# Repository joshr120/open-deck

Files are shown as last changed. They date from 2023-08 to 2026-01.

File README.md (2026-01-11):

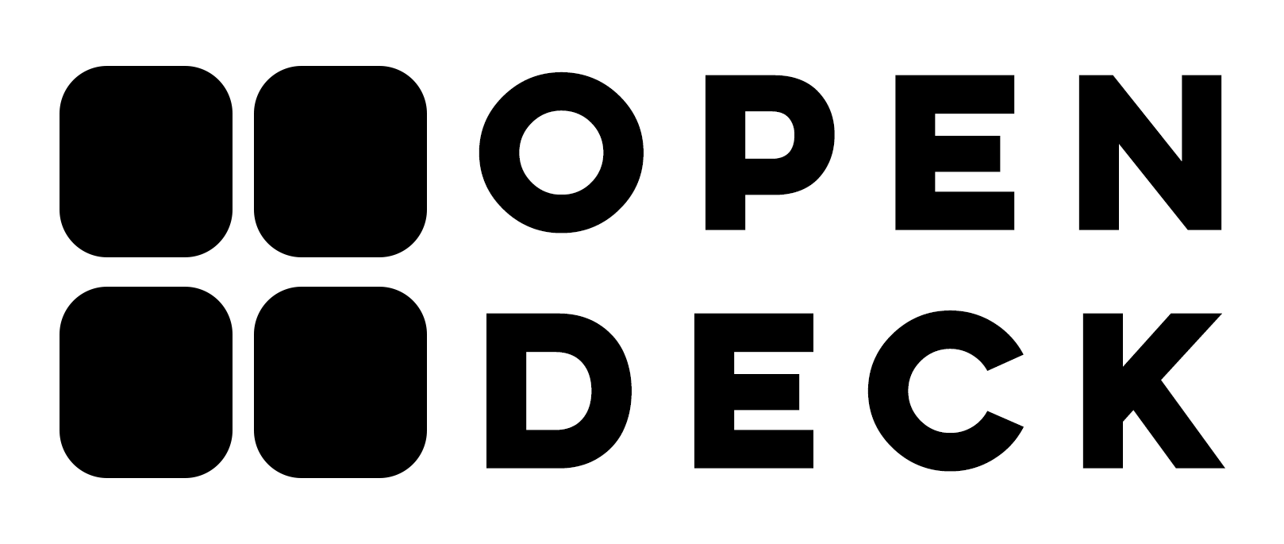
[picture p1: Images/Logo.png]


# Open Deck

## Parts and fully assembled units can be purchased Here: [https://thingsbyjosh.com/products/open-deck-macro-keyboard](https://thingsbyjosh.com/products/open-deck-macro-keyboard)  
<br>

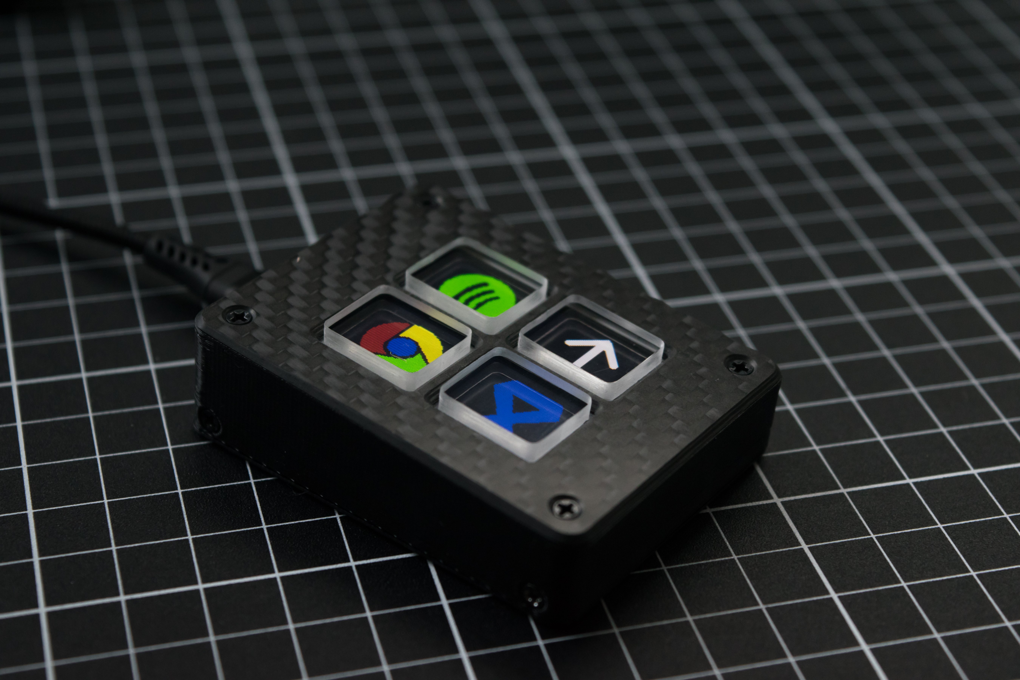
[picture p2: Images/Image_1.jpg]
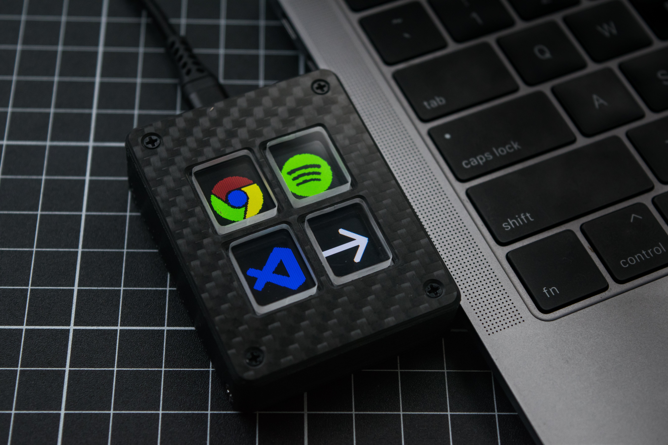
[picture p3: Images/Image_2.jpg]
⠀⠀⠀⠀⠀⠀⠀

Open Deck is a low cost open source macro keyboard with a customizable image behind every key.

Open Deck is an open source macro keyboard designed to be a cheaper alternative to the stream deck. It has software to easily change the images as well as the macros assigned to each button. The folder Structure allows 6 different apps to be configured with 3 macro keys each. The software allows the open deck to update with whatever app is open as well as open an app when buttons are pressed.

An easy to use interface allows you to easily upload and set macros.

MQTT Support to interface with home assistant.

Full Video and build guide here: https://youtu.be/SCIMHQAToSw

# Software:

## GUI Interface

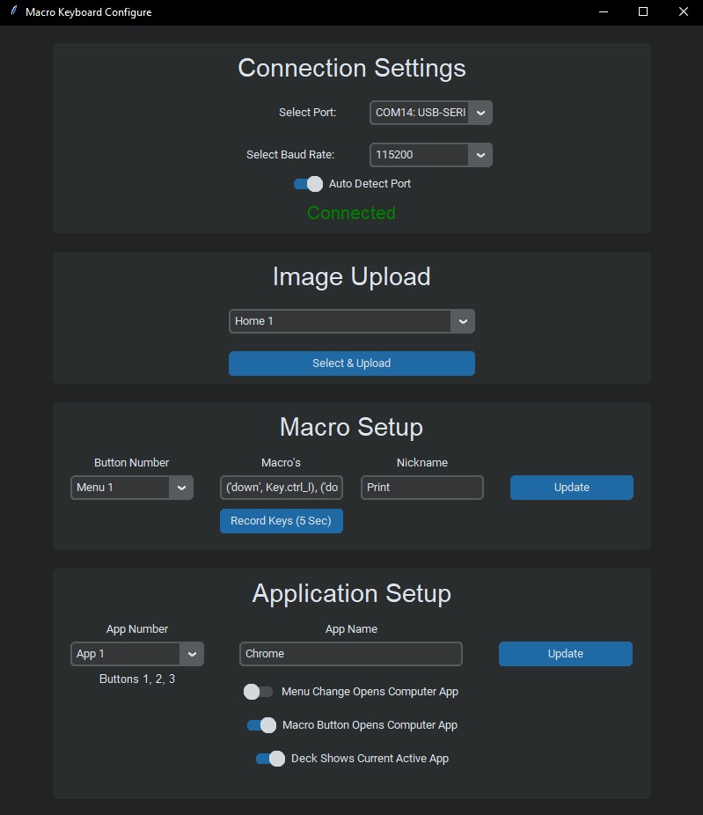
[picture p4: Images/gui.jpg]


Provided is a pre-compiled program for windows and mac as well as all the source code (written in python). Extract the zipped folder and run the .exe (or mac equivalent), no python libary installs required.

The Open Deck communicates with a PC over a serial USB connection. The software can automatically detect and connect to the Open Deck when it is plugged in.

The program is first used to upload images and set the macro's. After that it runs in the background to send keystrokes when the buttons are pressed.

Note: the automatic window switching only works on windows currently and the macOS pre-compiled GUI has only been tested on macOS Big Sur 11.6

## Uploading Images
The PC application makes it super easy to upload images. The files can be any size and the program does all of the conversion for you. At the moment each image can only be a single colour when uploaded through the GUI. When uploading an image the black part of the image will be shown in the chosen colour and the rest will be black. See Additional Features section for how to do images with multiple colours.

The select & upload button will prompt the user to select an image from the file system as well as choose a colour from a colour picker.

## Setting Macros
The macros are sent using the python [pynput library] (https://pynput.readthedocs.io/en/latest/keyboard.html#controlling-the-keyboard). (Previous version used the python keyboard library but this had limitations)

If more complex macros are required I recommend setting it to some unused combination and then remapping this combination using something like auto hot key. (Not going to try re-invent the wheel here). Easier way to figure out the format or key names is to use the record keys button in the GUI and look at what is entered in the text box. For example the following input will output "test" when the macro is triggered:

<code>('down', 't'), ('up', 't'), ('down', 'e'), ('up', 'e'), ('down', 's'), ('up', 's'), ('down', 't'), ('up', 't')</code>

To do key combinations such as "control+shift" it would look like this:

<code>('down', Key.ctrl), ('down', Key.ctrl), ('down', Key.ctrl), ('down', 's'), ('up', 's'), ('up', Key.ctrl)</code> 

## Window Switching/application setup
One usefull feature on the open deck has is the ability to have the buttons change depending on which application is currently open as well. It can also open an app when a button on the open deck is pressed.

By inputting the application name for each menu of the open deck, the program will look for a window containing this name to either control the open deck or have the open deck control/activate this window.

On windows there are 3 settings for automatically switching windows and/or current open deck state.

- The first option will open the application on the computer when the corresponding folder is opened on the keypad.

- The second option will open the corresponding computer application when a shortcut is sent. This is usefull if you have multiple applciations open at once as it will make the correct application active before sending the keystrokes.

- The third option will change which set of macros are shown on the keypad depending on which computer application is currently active.

## Arduino
All of the code running on the ESP8266 on the Open Deck itself is using arduino. The images are stored as a bitmap in SPIFFS so that they remain after a power cycle and are not relient on a computer connection.

When a key is pressed it sends a correlated number (1-16) over serial to the program running on the computer. 

If you purchase a pre-made Open Deck it will come flashed with the default firmware and you will not need to touch any arduino code or install any libraries. 
> For more info on the software see the README in the Code folder

## Smart Home Control With MQTT:
The Open Deck can also be used as a smart home controller using MQTT. This can easily interface with home assitant without the Open-Deck only needing to be plugged in for power. Upload the example MQTT arduino sketch onto the Open Deck and enter your credentials in the code. 

A number 1-16 will be sent to the topic ```open_deck/buttons``` whenever the button is pressed.

Images can easily be uploaded using the GUI and will be saved localy on the Open Deck.

In the future I would like to integrate this setup into the GUI so you do not need to re-flash any firmware.

# Hardware
See the BOM for a full list of all of the required components. And support the project by buying parts or a full unit [here](https://thingsbyjosh.com/products/open-deck-macro-keyboard)

> If there is a particular item or set of items you would like to buy feel free to send me an email to [info@thingsbyjosh.com](info@thingsbyjosh.com).

Things of Note:

- The display is a 128x160 tft display. The exact display is quite important as the hole patten and pinout needs to fit the custom PCB's. (See BOM for Link)

- An ESP8266 is being used as the micro-controller as it is small, low cost, has enough flash memory to store all of the images as well as having WiFi to allow for additional features. Importantly for everything to fit this needs to be a WEMOS D1 Mini V4 with a USB-C Connector

- Low Profile M2 Screws used for clearance (Length is critical)

## 3D Printed Parts
All parts can be printed with no supports. Print in the orientation shown below:

Body:

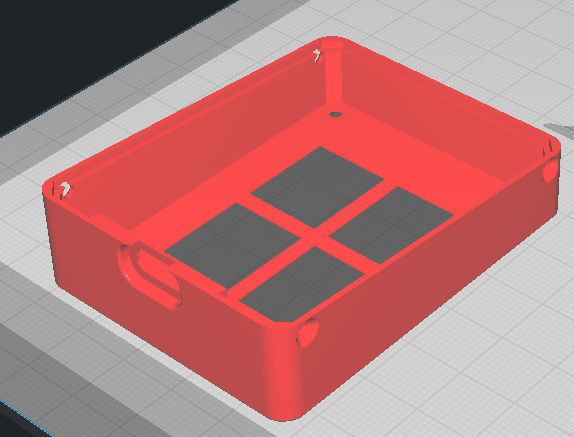
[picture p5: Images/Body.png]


Bottom Cover:

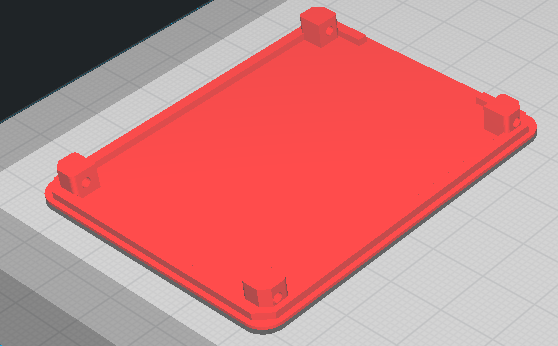
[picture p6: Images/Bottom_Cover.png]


Window Holder:

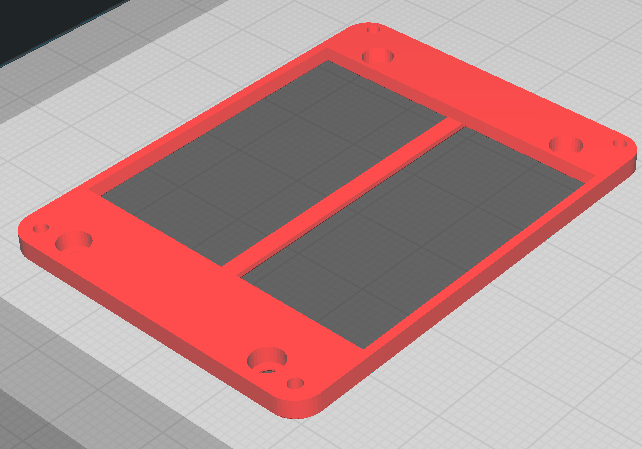
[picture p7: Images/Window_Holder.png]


Spacer:

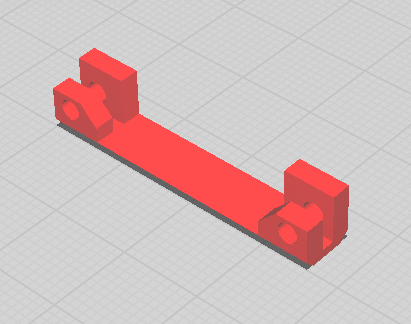
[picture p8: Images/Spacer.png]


## CNC Machined Parts
### Carbon Fibre Top Plate
The carbon top plate is made out of 1mm thick carbon fibre.

### Acrylic Key Caps
The 'Key Caps' are machined out of 4.5mm thick acrylic. They are all the same design.

These can also be made out of 1.5mm and 3mm laser cut acrylic glued together if you do not have access to a CNC. I have found the best glue for this is UV curable glue used for some phone screen protectors.

These could also potentially be 3D printed from clear resin and polished to get a transparent finish.

As with all the custom parts these are availale for purchase from [my store](https://thingsbyjosh.com/products/open-deck-macro-keyboard).

## PCB
The PCB folder contains a zipped folder of the GERBER files required to have the PCB manufactured. 

If you want to order them yourself you can support the project and order them here: [PCBWay.com](https://pcbway.com/g/heg1oh).

# Additional Features:
- If you want images with multiple colours these currently need to be manually entered into the arduino code. See the README in the Code folder for more info.

<br>
<br>

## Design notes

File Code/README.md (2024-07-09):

# Open Deck Software

## Parts and fully assembled units can be purchased Here: https://www.tindie.com/products/27756/  
<br>

# Software:
## Uploading Images
The PC application makes it super easy to upload images. The files can be any size and the program does all of the conversion for you. At the moment each image can only be a single colour when uploaded through the GUI. When uploading an image the black part of the image will be shown in the chosen colour and the rest will be black. See Additional Features section for how to do images with multiple colours.

## Arduino
All of the code running on the ESP8266 on the Open Deck itself is using arduino. The images are stored as a bitmap in SPIFFS so that they remain after a power cycle and are not relient on a computer connection.

When a key is pressed it sends a correlated number (1-16) over serial to the program running on the computer. 

## MQTT
Thanks to the WiFi enable esp8266 chip the Open Deck can also be used as a smart home controller using MQTT. This can easily interface with home assitant without the Open-Deck only needing to be plugged in for power. Upload the example MQTT arduino sketch onto the Open Deck and enter your credentials in the code. 

This version of the code also allows the orientation to be changed so that the cable can come out of the bottom and the display can tilt slightly upwares for wall mounting.

A number 1-16 will be sent to the topic ```open_deck/buttons``` whenever the button is pressed.

Images can easily be uploaded using the GUI and will be saved localy on the Open Deck.

In the future I would like to integrate this setup into the GUI so you do not need to re-flash any firmware.

# Additional Features:
If you want images with multiple colours these currently need to be manually entered into the arduino code. The bitmap in the correct format will be outputted when an image is uploaded using the source python file "full_gui.py". One image will needed to be made for each colour in the image. A pre-made example of this can be uncommented for a chrome logo. Final imges are 48x72 pixels stored as a bitmap. The last 3 bytes of the message sent over serial contain the RGB colour of the icon.

Replace:

        tft.drawBitmap(0,0,homes[1], 54, 70, homeColours[1]);  //comment out this line to use chrome mulit-colour example

With:

        /////////    Chrome Multi-colour example  ///////
          tft.drawBitmap(0,0,chrome_r, 54, 70, ST77XX_RED);   
          tft.drawBitmap(0,0,chrome_g, 54, 70, ST77XX_GREEN);
          tft.drawBitmap(0,0,chrome_b, 54, 70, ST77XX_BLUE);
          tft.drawBitmap(0,0,chrome_y, 54, 70, ST77XX_YELLOW);

Where chrome_r, chrome_g etc. are individual bitmaps of each coloured reigon stored in the bitmaps.h file. The colour of each bitmap can then manually be set (eg. ST77XX_RED, (RGR565 format)) 

Note:  When uploading one of the macro images two images will be printed. The second is a smaller version used for the key press effect.
        
<br>
<br>

# Notes:
- Feel free to reach out with any question/problems and I will try to help
- The sofware is still evolving and I am by no means a software engineer but I have been using it everyday for over 6 months without an major issues.
- For use with MacOS you may need to install the FTDI drivers from [here](https://ftdichip.com/Drivers/vcp-drivers/)

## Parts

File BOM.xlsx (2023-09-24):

Open Deck BOM
Buy Open Deck & Parts Here: (https://www.tindie.com/products/27756) | https://www.tindie.com/products/27756
Custom Parts:
Item: | QTY: | Link:
PCB | 1 | https://www.tindie.com/products/27756
Acrylic Key Caps | 4 | https://www.tindie.com/products/27756
Carbon Fibre Top Cover | 1 | https://www.tindie.com/products/27756
3D Printed Parts:
Item: | QTY:
Body | 1
Bottom Cover | 1
Spacer | 2
Window Holder | 1
Off The Shelf Parts:
Item: | QTY: | Link:
ESP8266 (D1 Mini V4) | 1 | AliExpress (https://www.aliexpress.com/item/32831353752.html)
1.8" TFT Display | 1 | AliExpress (https://www.aliexpress.com/item/32996979276.html)
Switches | 4 | AliExpress (https://www.aliexpress.com/item/4001343124925.html)
10kΩ 0805 Resistor | 2 | AliExpress (https://www.aliexpress.com/item/2011573653.html)
Low Profile M2*10mm | 4 | AliExpress (https://www.aliexpress.com/item/1005005264656436.html)
M2 Nut | 4 | AliExpress (https://www.aliexpress.com/item/32977174437.html)
M2*6mm Countersunk Screw | 8 | AliExpress (https://www.aliexpress.com/item/33043885403.html)
Non-slip Feet (0.5mm) | 1 | AliExpress (https://www.aliexpress.com/item/1005003972280242.html)

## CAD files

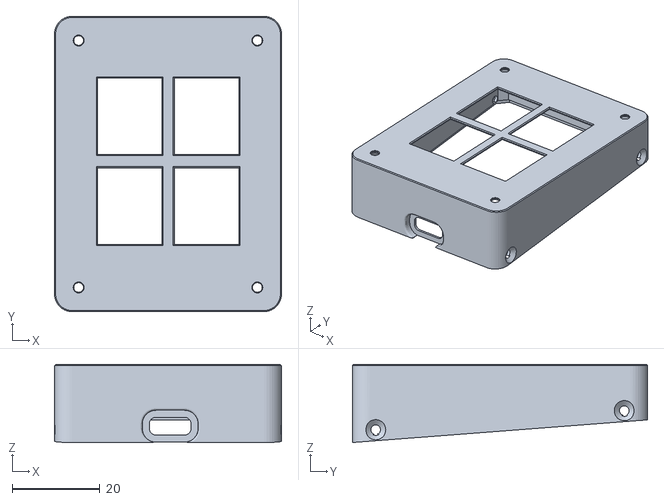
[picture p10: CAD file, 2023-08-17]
Hardware/3D Printed Parts/Body For Carbon (4.5mm acrylic).stl
51.7 x 67.2 x 17.8

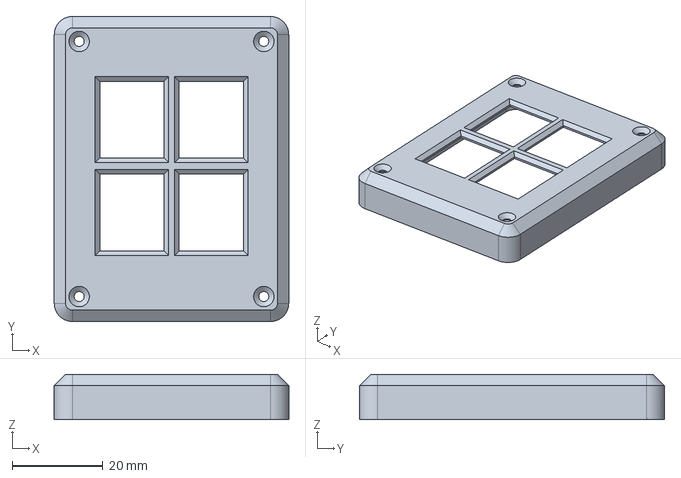
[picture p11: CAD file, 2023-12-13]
Hardware/Aluminium Version/Macro Keyboard Aluminium Top.step
51.7 x 67.2 x 10.0 mm

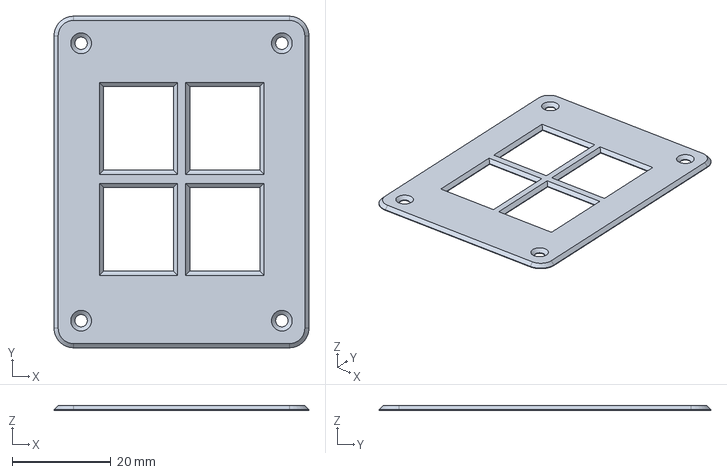
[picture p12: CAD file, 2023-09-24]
Hardware/CNC Machined Parts/Carbon Fibre Top Plate.step
51.7 x 67.2 x 1.00 mm

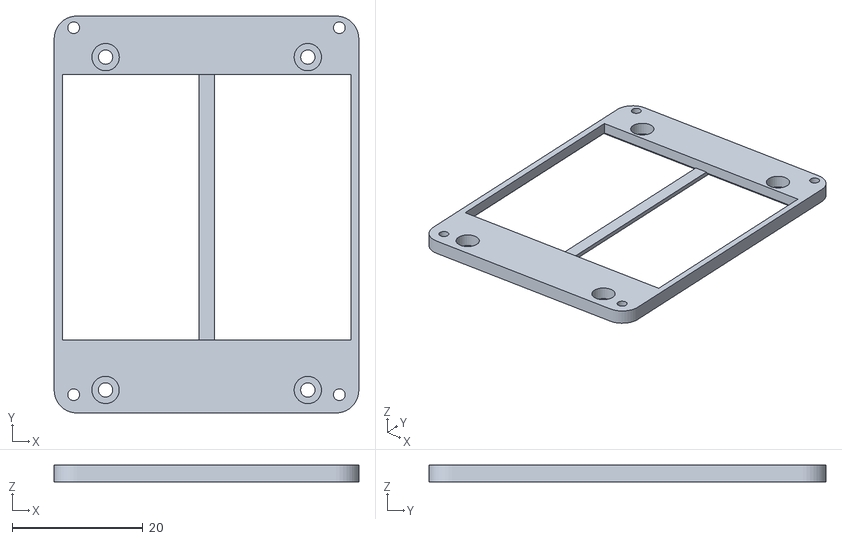
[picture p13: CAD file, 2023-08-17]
Hardware/3D Printed Parts/Window Holder (4.5mm windows).stl
46.7 x 60.8 x 2.55

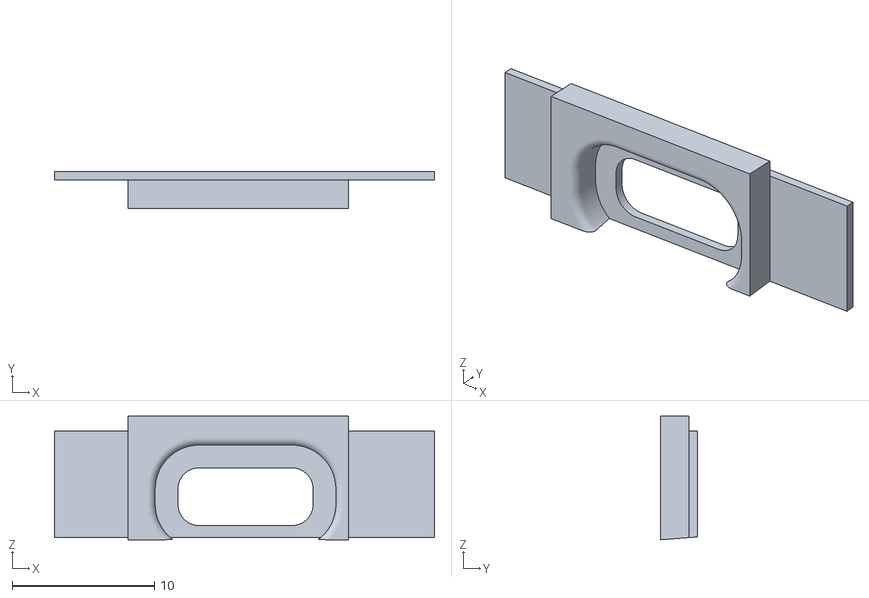
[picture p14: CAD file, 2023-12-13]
Hardware/Aluminium Version/USB housing.stl
26.7 x 2.60 x 8.68

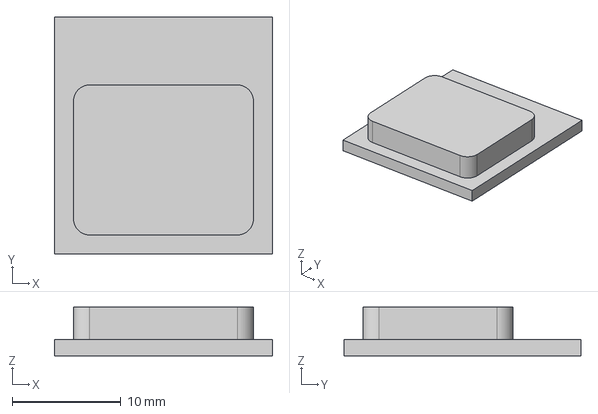
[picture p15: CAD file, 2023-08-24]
Hardware/CNC Machined Parts/Acrylic Keycap.step
20.1 x 21.8 x 4.50 mm

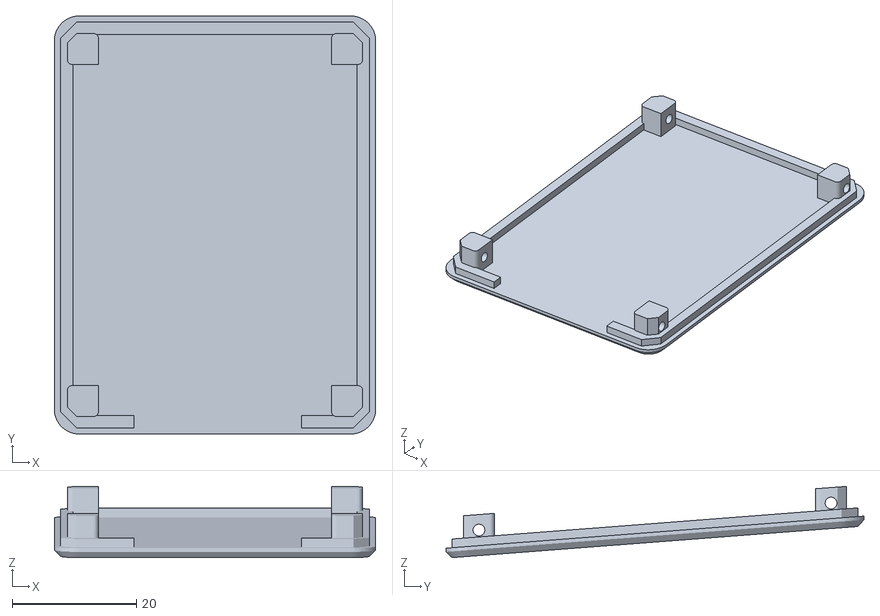
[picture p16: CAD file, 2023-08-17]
Hardware/3D Printed Parts/Bottom Plate (4.5mm acrylic).stl
51.7 x 67.2 x 11.5

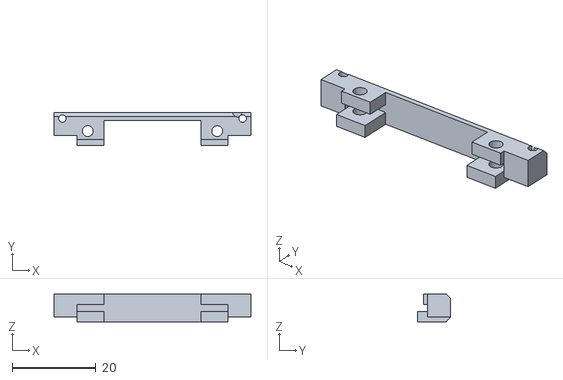
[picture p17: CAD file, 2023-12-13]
Hardware/Aluminium Version/Aluminium Front Spacer.stl
47.2 x 8.00 x 6.60

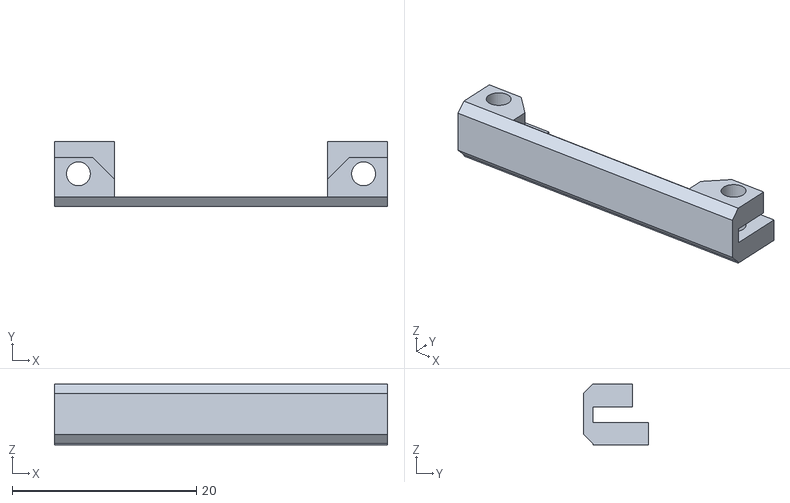
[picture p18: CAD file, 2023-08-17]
Hardware/3D Printed Parts/Microswitch Spacer 2.stl
36.2 x 7.04 x 6.60

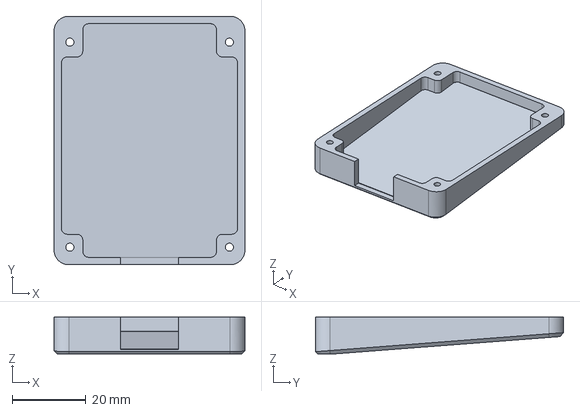
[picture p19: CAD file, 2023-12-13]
Hardware/Aluminium Version/Macro Keyboard Aluminium Bottom.step
51.7 x 67.2 x 10.0 mm

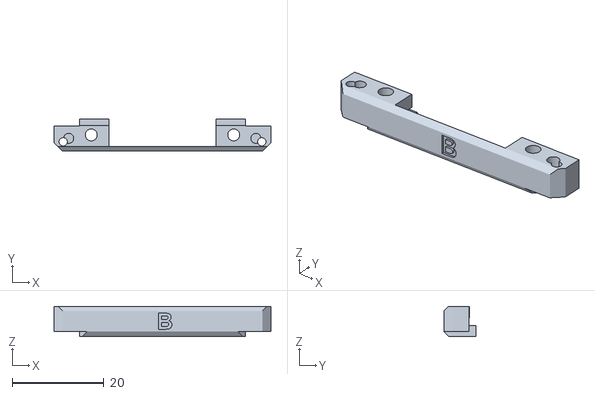
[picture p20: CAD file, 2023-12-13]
Hardware/Aluminium Version/Aluminium Back Spacer.stl
47.2 x 7.04 x 6.60

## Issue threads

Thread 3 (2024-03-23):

Can you support more integrated devices?

lukedoomer, 2024-03-23:
Your design is awesome. I hope you can support more common esp32-s3 devices. for example [wt32-sc01](https://www.openhasp.com/0.6.1/devices/wt32-sc01/) by wireless tag

joshr120, 2024-03-23:
Not too sure what you mean by support more devices? This has a custom PCB specifically designed for the ESP8266 Wemos D1 V3 so you can't really just drop in a different microcontroller. The code would be fairly easy to get working on an ESP32 and if I do make an updated version it would probably use an ESP32

Closed 2024-06-06.

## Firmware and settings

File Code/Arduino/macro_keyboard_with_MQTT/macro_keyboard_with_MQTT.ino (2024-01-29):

///////////////////////////////
////////  OPEN DECK   /////////
///////////////////////////////

/////  MQTT Setup ///////
// Using: https://github.com/plapointe6/EspMQTTClient

#include "EspMQTTClient.h"

EspMQTTClient client(
  "YOUR_SSID",  //WIFI SSID
  "YOUR_PASSWORD",  //WIFI Password
  "192.168.1.204",  // MQTT Broker server ip (REPLACE WITH YOURS)
  "MQTT_USERNAME",   // Can be omitted if not needed
  "MQTT_USERNAME",   // Can be omitted if not needed
  "Open Deck"      // Client name that uniquely identify your device
);

//////  end MQTT setup ///////


/////// Set Screen Orientation////////
int orientation = 0; //2 for normal 0 for inverted
/////////////////////////////////////

#include <Adafruit_GFX.h>    // Core graphics library
#include <Adafruit_ST7735.h> // Hardware-specific library for ST7735
#include <Adafruit_ST7789.h> // Hardware-specific library for ST7789
#include <SPI.h>

#include <FS.h> //for saving in spiffs
#include "bitmap.h"
#include "home_bitmaps.h"
#include "menu_bitmaps.h"

#define TFT_CS     D8 
#define TFT_RST    D6  // Theoreically can set this to -1 use use arduino reset (wasnt working)
#define TFT_DC     D2



////////////////////////////
//      PCB Pinouts       //
////////////////////////////
#define TL D0
#define BL A0   //Note Analog pin being used with pull up resistor as run out of digital inputs (Fix in future versions)
#define TR D1
#define BR D4


// For 1.44" and 1.8" TFT with ST7735 use
Adafruit_ST7735 tft = Adafruit_ST7735(TFT_CS, TFT_DC, TFT_RST);

int pageState = 1;
int lastPageState = 0;

int menuState = 0;
int lastMenuState = 0;

int incomingByte = 0;

#define BUFF_LEN 490
unsigned char img1 [BUFF_LEN];
unsigned char colour [3];

//Colours stored in RBG565 format (see https://www.barth-dev.de/online/rgb565-color-picker/)
//These are the default colours, once updated using the GUI stored and loaded in from SPIFFS
uint16_t homeColours [] = {0, 0xF800, 0x07E0, 0x001F, 0xFC18, 0xFFE0, 0x07FF};
uint16_t menuColours [] = {0, 0xF800, 0xF800, 0xF800, 0x07E0, 0x07E0, 0x07E0, 0x001F, 0x001F, 0x001F, 0xFC18, 0xFC18, 0xFC18, 0xFFE0, 0xFFE0, 0xFFE0, 0x07FF, 0x07FF, 0x07FF};

unsigned char writeBuffer [492]; //array to store in spiffs 490 bits of the image and 2 bit on the end of the colour

void setup(void) {
  pinMode(TL, INPUT);
  pinMode(TR, INPUT_PULLUP);
  pinMode(BL, INPUT);
  pinMode(BR, INPUT_PULLUP);
  Serial.begin(115200);
  Serial.setTimeout(500);
  tft.initR(INITR_BLACKTAB);   // initialize a ST7735S chip, black tab
  tft.fillScreen(ST77XX_BLACK);

  //Serial.println("Initialized");

  delay(100);

  tft.setRotation(orientation);  //invert diaply orientation

  readFromSpiffs();

}

//MQTT on connection
void onConnectionEstablished() {
  Serial.println("MQTT Established");

//  client.subscribe("open_deck/buttons", [] (const String &payload)  {
//    Serial.println(payload);
//  });

  client.publish("open_deck/buttons", "Connected");
}

void loop() {
    client.loop(); //MQTT

    bool TLState = 0;
    bool BRState = 0;
    bool BLState = 0;
    bool TRState = 0; 
    int BLVal = 1000;
    int TRVal = 1000;
    
    if (orientation == 2){
      TLState = digitalRead(TL);
      BRState = digitalRead(BR);
      TRState = digitalRead(TR);
      BLVal = analogRead(BL);  //analog read as not enough digital pins :(
      BLState = (BLVal>500);
    } else if (orientation == 0){
      TLState = digitalRead(BR);
      BRState = digitalRead(TL);
      BLState = digitalRead(TR);
      TRVal = analogRead(BL);  //analog read as not enough digital pins :(
      TRState = (TRVal>500);
    }

    //page 1
    if (pageState == 1 && !TLState){  //top left page 1
      //Serial.println("Entering Chrome Menu");
      menuState = 1;
      pageState = 0;
      lastPageState = 0;
    } else if (pageState == 1 && !TRState){ //top Right page 1
      menuState = 2;
      pageState = 0;
      lastPageState = 0;
    } else if (pageState == 1 && !BLState){  //Bottom left page 1
      menuState = 3;
      pageState = 0;
      lastPageState = 0;
    } else if (pageState == 1 && !BRState){  //next page pressed page 1
      pageState = 2;
    } else if ((pageState == 0 && menuState <= 3) && !BLState){  //home pressed from menu 1-3
      pageState = 1;
      menuState = 0;
      lastMenuState = 0;
    }
    
    //page 2
    else if (pageState == 2 && !TLState){  //top left page 2
      menuState = 4;
      pageState = 0;
      lastPageState = 0;
    } else if (pageState == 2 && !TRState){ //top Right page 2
      menuState = 5;
      pageState = 0;
      lastPageState = 0;
    } else if (pageState == 2 && !BLState){  //prev page
      pageState = 1;
    } else if (pageState == 2 && !BRState){  //bottom right page 2
      menuState = 6;
      pageState = 0;
      lastPageState = 0;
    } else if ((pageState == 0 && menuState >= 4) && !BLState){  //home pressed from menu 4-6
      pageState = 2;
      menuState = 0;
      lastMenuState = 0;
    }

    //Menu 1        
    else if (menuState == 1 && !TLState){
      tft.fillRect(0,0,54, 70, ST77XX_BLACK);
      tft.drawBitmap(0,0,menus_small[1], 54, 70, menuColours[1]);
      Serial.println("1");
      client.publish("open_deck/buttons", "1");
      delay(150);
      if (orientation == 2){
        while(!TLState){ TLState = digitalRead(TL);delay(10);}
      }  else if (orientation == 0){ //work around for analog read 
        while(!TLState){ TLState = digitalRead(BR);delay(10);}
      }
      tft.drawBitmap(0,0,menus[1], 54, 70, menuColours[1], ST77XX_BLACK);
      
    } else if (menuState == 1 && !TRState){
      tft.fillRect(74, 0, 54, 70, ST77XX_BLACK);
      tft.drawBitmap(74,0,menus_small[2], 54, 70, menuColours[2]);
      Serial.println("2");
      client.publish("open_deck/buttons", "2");
      delay(150);
      if (orientation == 2){
        while(!TRState){ TRState = digitalRead(TR);delay(10);}
      }  else if (orientation == 0){ //work around for analog read 
        while(!TRState){ TRState =  TRVal = analogRead(BL); TRState = (TRVal>500); delay(10);}
      }
      tft.drawBitmap(74,0,menus[2], 54, 70, menuColours[2], ST77XX_BLACK);
      
    } else if (menuState == 1 && !BRState){
      tft.fillRect(74, 90, 54, 70, ST77XX_BLACK);
      tft.drawBitmap(74, 90, menus_small[3], 54, 70, menuColours[3]);
      Serial.println("3");
      client.publish("open_deck/buttons", "3");
      delay(150);
      if (orientation == 2){
        while(!BRState){ BRState = digitalRead(BR);delay(10);}
      }  else if (orientation == 0){ //work around for analog read 
        while(!BRState){ BRState = digitalRead(TL);delay(10);}
      }
      tft.drawBitmap(74,90,menus[3], 54, 70, menuColours[3], ST77XX_BLACK);
    }

    //Menu 2
    else if (menuState == 2 && !TLState){
      tft.fillRect(0,0,54, 70, ST77XX_BLACK);
      tft.drawBitmap(0,0,menus_small[4], 54, 70, menuColours[4], ST77XX_BLACK);
      Serial.println("4");
      client.publish("open_deck/buttons", "4");
      delay(150);
      if (orientation == 2){
        while(!TLState){ TLState = digitalRead(TL);delay(10);}
      }  else if (orientation == 0){ //work around for analog read 
        while(!TLState){ TLState = digitalRead(BR);delay(10);}
      }
      tft.drawBitmap(0,0,menus[4], 54, 70, menuColours[4], ST77XX_BLACK);
      
    } else if (menuState == 2 && !TRState){
      tft.fillRect(74, 0, 54, 70, ST77XX_BLACK);
      tft.drawBitmap(74,0,menus_small[5], 54, 70, menuColours[5]);
      Serial.println("5");
      client.publish("open_deck/buttons", "5");
      delay(150);
      if (orientation == 2){
        while(!TRState){ TRState = digitalRead(TR);delay(10);}
      }  else if (orientation == 0){ //work around for analog read 
        while(!TRState){ TRState =  TRVal = analogRead(BL); TRState = (TRVal>500); delay(10);}
      }
      tft.drawBitmap(74,0,menus[5], 54, 70, menuColours[5], ST77XX_BLACK);
      
    } else if (menuState == 2 && !BRState){
      tft.fillRect(74, 90, 54, 70, ST77XX_BLACK);
      tft.drawBitmap(74, 90, menus_small[6], 54, 70, menuColours[6]);
      Serial.println("6");
      client.publish("open_deck/buttons", "6");
      delay(150);
      if (orientation == 2){
        while(!BRState){ BRState = digitalRead(BR);delay(10);}
      }  else if (orientation == 0){ //work around for analog read 
        while(!BRState){ BRState = digitalRead(TL);delay(10);}
      }
      tft.drawBitmap(74,90,menus[6], 54, 70, menuColours[6], ST77XX_BLACK);
    }

    //Menu 3
    else if (menuState == 3 && !TLState){
      tft.fillRect(0,0,54, 70, ST77XX_BLACK);
      tft.drawBitmap(0,0,menus_small[7], 54, 70, menuColours[7]);
      Serial.println("7");
      client.publish("open_deck/buttons", "7");
      delay(150);
      if (orientation == 2){
        while(!TLState){ TLState = digitalRead(TL);delay(10);}
      }  else if (orientation == 0){ //work around for analog read 
        while(!TLState){ TLState = digitalRead(BR);delay(10);}
      }
      tft.drawBitmap(0,0,menus[7], 54, 70, menuColours[7], ST77XX_BLACK);
      
    } else if (menuState == 3 && !TRState){
      tft.fillRect(74, 0, 54, 70, ST77XX_BLACK);
      tft.drawBitmap(74,0,menus_small[8], 54, 70, menuColours[8]);
      Serial.println("8");
      client.publish("open_deck/buttons", "8");
      delay(150);
      if (orientation == 2){
        while(!TRState){ TRState = digitalRead(TR);delay(10);}
      }  else if (orientation == 0){ //work around for analog read 
        while(!TRState){ TRState =  TRVal = analogRead(BL); TRState = (TRVal>500); delay(10);}
      }
      tft.drawBitmap(74,0,menus[8], 54, 70, menuColours[8], ST77XX_BLACK);
      
    } else if (menuState == 3 && !BRState){
      tft.fillRect(74, 90, 54, 70, ST77XX_BLACK);
      tft.drawBitmap(74, 90, menus_small[9], 54, 70, menuColours[9]);
      Serial.println("9");
      client.publish("open_deck/buttons", "9");
      delay(150);
      if (orientation == 2){
        while(!BRState){ BRState = digitalRead(BR);delay(10);}
      }  else if (orientation == 0){ //work around for analog read 
        while(!BRState){ BRState = digitalRead(TL);delay(10);}
      }
      tft.drawBitmap(74,90,menus[9], 54, 70, menuColours[9], ST77XX_BLACK);
    }

    //Menu 4 (task manger)
    else if (menuState == 4 && !TLState){
      tft.fillRect(0,0,54, 70, ST77XX_BLACK);
      tft.drawBitmap(0,0,menus_small[10], 54, 70, menuColours[10]);
      Serial.println("10");
      client.publish("open_deck/buttons", "10");
      delay(150);
      if (orientation == 2){
        while(!TLState){ TLState = digitalRead(TL);delay(10);}
      }  else if (orientation == 0){ //work around for analog read 
        while(!TLState){ TLState = digitalRead(BR);delay(10);}
      }
      tft.drawBitmap(0,0,menus[10], 54, 70, menuColours[10], ST77XX_BLACK);
      
    } else if (menuState == 4 && !TRState){
      tft.fillRect(74, 0, 54, 70, ST77XX_BLACK);
      tft.drawBitmap(74,0,menus_small[11], 54, 70, menuColours[11]);
      Serial.println("11");
      client.publish("open_deck/buttons", "11");
      delay(150);
      if (orientation == 2){
        while(!TRState){ TRState = digitalRead(TR);delay(10);}
      }  else if (orientation == 0){ //work around for analog read 
        while(!TRState){ TRState =  TRVal = analogRead(BL); TRState = (TRVal>500); delay(10);}
      }
      tft.drawBitmap(74,0,menus[11], 54, 70, menuColours[11], ST77XX_BLACK);
      
    } else if (menuState == 4 && !BRState){
      tft.fillRect(74, 90, 54, 70, ST77XX_BLACK);
      tft.drawBitmap(74, 90, menus_small[12], 54, 70, menuColours[12]);
      Serial.println("12");
      client.publish("open_deck/buttons", "12");
      delay(150);
      if (orientation == 2){
        while(!BRState){ BRState = digitalRead(BR);delay(10);}
      }  else if (orientation == 0){ //work around for analog read 
        while(!BRState){ BRState = digitalRead(TL);delay(10);}
      }
      tft.drawBitmap(74,90,menus[12], 54, 70, menuColours[12], ST77XX_BLACK);
    }

    //Menu 5
    else if (menuState == 5 && !TLState){
      tft.fillRect(0,0,54, 70, ST77XX_BLACK);
      tft.drawBitmap(0,0,menus_small[13], 54, 70, menuColours[13]);
      Serial.println("13");
      client.publish("open_deck/buttons", "13");
      delay(150);
      if (orientation == 2){
        while(!TLState){ TLState = digitalRead(TL);delay(10);}
      }  else if (orientation == 0){ //work around for analog read 
        while(!TLState){ TLState = digitalRead(BR);delay(10);}
      }
      tft.drawBitmap(0,0,menus[13], 54, 70, menuColours[13], ST77XX_BLACK);
      
    } else if (menuState == 5 && !TRState){
      tft.fillRect(74, 0, 54, 70, ST77XX_BLACK);
      tft.drawBitmap(74,0,menus_small[14], 54, 70, menuColours[14]);
      Serial.println("14");
      client.publish("open_deck/buttons", "14");
      delay(150);
      if (orientation == 2){
        while(!TRState){ TRState = digitalRead(TR);delay(10);}
      }  else if (orientation == 0){ //work around for analog read 
        while(!TRState){ TRState =  TRVal = analogRead(BL); TRState = (TRVal>500); delay(10);}
      }
      tft.drawBitmap(74,0,menus[14], 54, 70, menuColours[14], ST77XX_BLACK);
      //delay(100);
      
    } else if (menuState == 5 && !BRState){
      tft.fillRect(74, 90, 54, 70, ST77XX_BLACK);
      tft.drawBitmap(74, 90, menus_small[15], 54, 70, menuColours[15]);
      Serial.println("15");
      client.publish("open_deck/buttons", "15");
      delay(150);
      if (orientation == 2){
        while(!BRState){ BRState = digitalRead(BR);delay(10);}
      }  else if (orientation == 0){ //work around for analog read 
        while(!BRState){ BRState = digitalRead(TL);delay(10);}
      }
      tft.drawBitmap(74,90,menus[15], 54, 70, menuColours[15], ST77XX_BLACK);
    }
    
    //Menu 6
    else if (menuState == 6 && !TLState){
      tft.fillRect(0,0,54, 70, ST77XX_BLACK);
      tft.drawBitmap(0,0,menus_small[16], 54, 70, menuColours[16]);
      Serial.println("16");
      client.publish("open_deck/buttons", "16");
      delay(150);
      if (orientation == 2){
        while(!TLState){ TLState = digitalRead(TL);delay(10);}
      }  else if (orientation == 0){ //work around for analog read 
        while(!TLState){ TLState = digitalRead(BR);delay(10);}
      }
      tft.drawBitmap(0,0,menus[16], 54, 70, menuColours[16], ST77XX_BLACK);
      
    } else if (menuState == 6 && !TRState){
      tft.fillRect(74, 0, 54, 70, ST77XX_BLACK);
      tft.drawBitmap(74,0,menus_small[17], 54, 70, menuColours[17]);
      Serial.println("17");
      client.publish("open_deck/buttons", "17");
      delay(150);
      if (orientation == 2){
        while(!TRState){ TRState = digitalRead(TR);delay(10);}
      }  else if (orientation == 0){ //work around for analog read 
        while(!TRState){ TRState =  TRVal = analogRead(BL); TRState = (TRVal>500); delay(10);}
      }
      tft.drawBitmap(74,0,menus[17], 54, 70, menuColours[17], ST77XX_BLACK);
      
    } else if (menuState == 6 && !BRState){
      tft.fillRect(74, 90, 54, 70, ST77XX_BLACK);
      tft.drawBitmap(74, 90, menus_small[18], 54, 70, menuColours[18]);
      Serial.println("18");
      client.publish("open_deck/buttons", "18");
      delay(150);
      if (orientation == 2){
        while(!BRState){ BRState = digitalRead(BR);delay(10);}
      }  else if (orientation == 0){ //work around for analog read 
        while(!BRState){ BRState = digitalRead(TL);delay(10);}
      }
      tft.drawBitmap(74,90,menus[18], 54, 70, menuColours[18], ST77XX_BLACK);
    }
    
    screenUpdate();

    //received serial data so call function to read the imcomming data and save it to spiffs
    if (Serial.available() > 0) {
      imageImport();  //received serial 
      //force refresh because of weird behav of "button press" when serial receive (May be fixed?)
      //pageState = 1;
      //lastPageState = 0;
    }

    
    delay(20);
}

void screenUpdate() {

  ///update one of the home screens
  if (pageState != lastPageState && (pageState > 0)){  
    tft.fillScreen(ST77XX_BLACK);
    lastPageState = pageState;
    if (pageState == 1){

      /////////    Chrome Multi-colour example  ///////
//      tft.drawBitmap(0,0,chrome_r, 54, 70, ST77XX_RED);   
//      tft.drawBitmap(0,0,chrome_g, 54, 70, ST77XX_GREEN);
//      tft.drawBitmap(0,0,chrome_b, 54, 70, ST77XX_BLUE);
//      tft.drawBitmap(0,0,chrome_y, 54, 70, ST77XX_YELLOW);
      /////////              END              //////////

      tft.drawBitmap(0,0,homes[1], 54, 70, homeColours[1]);  //comment out this line and uncomment mulit-colour example to use chrome mulit-colour example
      tft.drawBitmap(74,0,homes[2], 54, 70, homeColours[2]);
      tft.drawBitmap(0,90,homes[3], 54, 70, homeColours[3]);
      
      tft.drawBitmap(74,90,nextPage, 54, 70, ST77XX_WHITE);
      
    } else if (pageState == 2){
      tft.drawBitmap(0,0,homes[4], 54, 70, homeColours[4]);
      tft.drawBitmap(74,0,homes[5], 54, 70, homeColours[5]);
      tft.drawBitmap(74,90,homes[6], 54, 90, homeColours[6]);

      tft.drawBitmap(0,90,prevPage, 54, 70, ST77XX_WHITE);
    }
    delay(150);
  } 
  
  //update home of the menus
  else if (menuState != lastMenuState){
    lastMenuState = menuState;
    tft.fillScreen(ST77XX_BLACK);
    tft.drawBitmap(0,90,homeIcon, 54, 70, ST77XX_WHITE);
    if (menuState == 1){  //Folder 1
      Serial.println("Menu: 1");
      tft.drawBitmap(0,0,menus[1], 54, 70, menuColours[1]);
      tft.drawBitmap(74,0,menus[2], 54, 70, menuColours[2]);
      tft.drawBitmap(74,90,menus[3], 54, 70, menuColours[3]);
    } else if (menuState == 2){ //Folder 2
      Serial.println("Menu: 2");
      tft.drawBitmap(0,0,menus[4], 54, 70, menuColours[4]);
      tft.drawBitmap(74,0,menus[5], 54, 70, menuColours[5]);
      tft.drawBitmap(74,90,menus[6], 54, 70, menuColours[6]);
    } else if (menuState == 3){ //Folder 3
      Serial.println("Menu: 3");
      tft.drawBitmap(0,0,menus[7], 54, 70, menuColours[7]);
      tft.drawBitmap(74,0,menus[8], 54, 70, menuColours[8]);
      tft.drawBitmap(74,90,menus[9], 54, 70, menuColours[9]);
    } else if (menuState == 4){ //Folder 4
      Serial.println("Menu: 4");
      tft.drawBitmap(0,0,menus[10], 54, 70, menuColours[10]);
      tft.drawBitmap(74,0,menus[11], 54, 70, menuColours[11]);
      tft.drawBitmap(74,90,menus[12], 54, 70, menuColours[12]);
    } else if (menuState == 5){ //Folder 5
      Serial.println("Menu: 5");
      tft.drawBitmap(0,0,menus[13], 54, 70, menuColours[13]);
      tft.drawBitmap(74,0,menus[14], 54, 70, menuColours[14]);
      tft.drawBitmap(74,90,menus[15], 54, 70, menuColours[15]);
    } else if (menuState == 6){  //Folder 6
      Serial.println("Menu: 6");
      tft.drawBitmap(0,0,menus[16], 54, 70, menuColours[16]);
      tft.drawBitmap(74,0,menus[17], 54, 70, menuColours[17]);
      tft.drawBitmap(74,90,menus[18], 54, 70, menuColours[18]);
    }
    delay(150);
  }
}
  
word ConvertRGB( byte R, byte G, byte B)
{
  return ( ((R & 0xF8) << 8) | ((G & 0xFC) << 3) | (B >> 3) );
}
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

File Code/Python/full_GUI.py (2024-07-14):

from imaplib import Commands
from tkinter import *
from tkinter import ttk
from tkinter import filedialog
from tkinter.colorchooser import askcolor
import tkinter
import customtkinter
import serial
import serial.tools.list_ports
import math

# import keyboard
from pynput.keyboard import Listener, Controller, Key, KeyCode  #replaces keyboard library (WIP)

import time

import pickle

import pygetwindow as gw #for window switching (windows only)

import numpy as np
import cv2

from threading import *

# open a pickle file
filename = 'data.pk'  #pickle file to save the data

ser = serial.Serial()

COMports = []

val = b''

prevPort = "Select"

#Defaults, New values are stored in data.pk
switchStates = ["off", "on", "on", "on"]

customtkinter.set_appearance_mode("dark")
customtkinter.set_default_color_theme("blue") 

BUTTON_OPTIONS = ["Menu 1", "Menu 2", "Menu 3", "Menu 4", "Menu 5", "Menu 6", "Menu 7", "Menu 8", "Menu 9", "Menu 10", "Menu 11", "Menu 12", "Menu 13", "Menu 14", "Menu 15", "Menu 16", "Menu 17", "Menu 18"]

HOME_OPTIONS = ["App 1", "App 2", "App 3", "App 4", "App 5", "App 6"]

OPTIONS = [ "Home 1","Home 2","Home 3","Home 4","Home 5","Home 6","Menu 1","Menu 2","Menu 3","Menu 4","Menu 5","Menu 6","Menu 7","Menu 8","Menu 9","Menu 10","Menu 11","Menu 12","Menu 13","Menu 14","Menu 15","Menu 16","Menu 17","Menu 18"]

#remove this in future and just edit name (current way is dumb, just for testing)
name_dict = { "Home 1": b'home_1\n',"Home 2": b'home_2\n',"Home 3": b'home_3\n',"Home 4": b'home_4\n',"Home 5": b'home_5\n',"Home 6": b'home_6\n',"Menu 1": b'menu_1\n',"Menu 2": b'menu_2\n',"Menu 3": b'menu_3\n',"Menu 4": b'menu_4\n',"Menu 5": b'menu_5\n',"Menu 6": b'menu_6\n',"Menu 7": b'menu_7\n',"Menu 8": b'menu_8\n',"Menu 9": b'menu_9\n',"Menu 10": b'menu_10\n',"Menu 11": b'menu_11\n',"Menu 12": b'menu_12\n',"Menu 13": b'menu_13\n',"Menu 14": b'menu_14\n',"Menu 15": b'menu_15\n',"Menu 16": b'menu_16\n',"Menu 17": b'menu_17\n',"Menu 18": b'menu_18\n'}


#Defaults, New values are stored in data.pk
key_dict = {
1: ["('down', 't'), ('up', 't'), ('down', 'e'), ('up', 'e'), ('down', 's'), ('up', 's'), ('down', 't'), ('up', 't')", "Description"],
2: ["('down', 't'), ('up', 't'), ('down', 'e'), ('up', 'e'), ('down', 's'), ('up', 's'), ('down', 't'), ('up', 't')", "Description"],
3: ["('down', 't'), ('up', 't'), ('down', 'e'), ('up', 'e'), ('down', 's'), ('up', 's'), ('down', 't'), ('up', 't')", "Description"],
4: ["('down', 't'), ('up', 't'), ('down', 'e'), ('up', 'e'), ('down', 's'), ('up', 's'), ('down', 't'), ('up', 't')", "Description"],
5: ["('down', 't'), ('up', 't'), ('down', 'e'), ('up', 'e'), ('down', 's'), ('up', 's'), ('down', 't'), ('up', 't')", "Description"],
6: ["('down', 't'), ('up', 't'), ('down', 'e'), ('up', 'e'), ('down', 's'), ('up', 's'), ('down', 't'), ('up', 't')", "Description"],
7: ["('down', 't'), ('up', 't'), ('down', 'e'), ('up', 'e'), ('down', 's'), ('up', 's'), ('down', 't'), ('up', 't')", "Description"],
8: ["('down', 't'), ('up', 't'), ('down', 'e'), ('up', 'e'), ('down', 's'), ('up', 's'), ('down', 't'), ('up', 't')", "Description"],
9: ["('down', 't'), ('up', 't'), ('down', 'e'), ('up', 'e'), ('down', 's'), ('up', 's'), ('down', 't'), ('up', 't')", "Description"],
10:["('down', 't'), ('up', 't'), ('down', 'e'), ('up', 'e'), ('down', 's'), ('up', 's'), ('down', 't'), ('up', 't')", "Description"],
11:["('down', 't'), ('up', 't'), ('down', 'e'), ('up', 'e'), ('down', 's'), ('up', 's'), ('down', 't'), ('up', 't')", "Description"],
12:["('down', 't'), ('up', 't'), ('down', 'e'), ('up', 'e'), ('down', 's'), ('up', 's'), ('down', 't'), ('up', 't')", "Description"],
13:["('down', 't'), ('up', 't'), ('down', 'e'), ('up', 'e'), ('down', 's'), ('up', 's'), ('down', 't'), ('up', 't')", "Description"],
14:["('down', 't'), ('up', 't'), ('down', 'e'), ('up', 'e'), ('down', 's'), ('up', 's'), ('down', 't'), ('up', 't')", "Description"],
15:["('down', 't'), ('up', 't'), ('down', 'e'), ('up', 'e'), ('down', 's'), ('up', 's'), ('down', 't'), ('up', 't')", "Description"],
16:["('down', 't'), ('up', 't'), ('down', 'e'), ('up', 'e'), ('down', 's'), ('up', 's'), ('down', 't'), ('up', 't')", "Description"],
17:["('down', 't'), ('up', 't'), ('down', 'e'), ('up', 'e'), ('down', 's'), ('up', 's'), ('down', 't'), ('up', 't')", "Description"],
18:["('down', 't'), ('up', 't'), ('down', 'e'), ('up', 'e'), ('down', 's'), ('up', 's'), ('down', 't'), ('up', 't')", "Description"],
}

#Defaults, New values are stored in data.pk
app_dict = {
1: "Chrome",
2: "",
3: "visual studio code",
4: "",
5: "fusion",
6: "arduino"
}
 
app = customtkinter.CTk()
app.geometry("800x900")
app.title("Macro Keyboard Configure")


##################################
#   Constantly refresh ports        #will change selection if current port no longer available as well as auto detect if no current port is currently selected
##################################
def updatePorts():
    global ser
    global COMports
    global prevPort
    ports = serial.tools.list_ports.comports()
    lastPorts = COMports
    COMports = ["Select"]
    for port, desc, hwid in sorted(ports):
        COMports.append(port+": "+desc)
    if (lastPorts != COMports):
        print("Port change detected")
        lastPorts = COMports
        portSelect.configure(values=COMports)
        # portSelect.values=COMports  #not working use .configure instead

        if (portSelect.get() not in COMports):  #issue here???????
            print("Old port no longer detected, un-selecting")
            portSelect.set("Select")
        if (portSelect.get() == "Select" and connectSwitch.get() == "on"):
            detectPort(ports)

    if (ser.isOpen() == False or prevPort != portSelect.get()):  #OR USER CHANGED BAUD RATE
        ser.close() #close current port beofre trying new one
        prevPort = portSelect.get()
        try:
            #check to see if already open first?????
            ser = serial.Serial((portSelect.get()).split(':', 1)[0], baudSelect.get())  #let user choose in future
            ser.timeout = 0.5
            connectLabel.configure(text="Connected", text_color="green")
        except:
            connectLabel.configure(text="Not Connected", text_color="red")

def detectPort(ports):
    for port, desc, hwid in sorted(ports):
        if ("USB-SERIAL CH340" in desc): #format device will appear as on windows
            print("Auto Detect:")
            print(port)
            portSelect.set(port)
        elif ("USB Serial" in desc): #format device will appear as on macOS
            print("Auto Detect:")
            print(port)
            portSelect.set(port)


##################################
#       get data from pickle
##################################
try:
    with open(filename, 'rb') as fi:
        key_dict, app_dict, switchStates = pickle.load(fi)
except:
    print("Could not import prev data")
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

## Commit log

2023-08-17 Hardware Added
    [Body For Carbon (4.5mm acrylic).stl, Bottom Plate (4.5mm acrylic).stl, Microswitch Spacer 2.stl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]
2023-08-21 STEP Files Added
    [Acrylic Keycap.step, BOM.xlsx, Carbon Fibre Top Plate.step]
2023-09-24 BOM Updated
    [BOM.xlsx, Carbon Fibre Top Plate.step]
2023-12-13 Added parts for alumium version
    [Aluminium Back Spacer.stl, Aluminium Front Spacer.stl, Macro Keyboard Aluminium Bottom.step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]
2024-07-09 Port selection improvement and auto detect fixes
    [full_GUI.py]
